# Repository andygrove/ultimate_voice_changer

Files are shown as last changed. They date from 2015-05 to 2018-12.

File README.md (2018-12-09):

# Ultimate Voice Changer Arduino Library

## What is this?

This is the official Arduino library for the Ultimate Voice Changer Arduino Shield, which is an open source hardware project that uses an MCP3208 ADC and an MCP4921 DAC with SPI communications to provide high quality voice sampling and real-time audio manipulation.

## Shield PCB

Eagle schematics and board layout for an Arduino Uno shield are included in this repository. Boards can also be purchased directly from OSH Park:

* [Ultimate Voice Changer PCB @ OSH Park](https://oshpark.com/shared_projects/ojPzRnSB)

## Component List

* [MCP3204](https://www.mouser.com/ProductDetail/579-MCP3204-CI-P)
* [MCP4921](https://www.mouser.com/ProductDetail/579-MCP4921-E-P)
* [Audio Jack](https://www.mouser.com/ProductDetail/502-35RAPC4BHN2)
* 1K resistor
* 1.5K resistor
* 330 ohm resistor
* 0.1 uF capacitor
* [10 uF electrolytic capacitor (2mm spacing)](https://www.mouser.com/ProductDetail/667-ECA-1HM100)
* [LED T1-3/4 (5mm) RED](https://www.mouser.com/ProductDetail/696-SLX-LX5093ID)
* [36-pin header](https://www.mouser.com/ProductDetail/538-22-28-4363)
* [10K Trimpot](https://www.sparkfun.com/products/9806)

## Example sketches

See the [examples](examples) directory for Dalek / ring modulator examples that mix voice input with a sine wave for robotic voice effects.

## Alternatives

I am no longer actively maintaining this project or providing support and I would suggest looking at the [Adafruit Wave Shield](https://learn.adafruit.com/wave-shield-voice-changer/overview) instead. They even have an example Dalek sketch.

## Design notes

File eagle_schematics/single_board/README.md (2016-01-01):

# Single Board Version

This is an experimental single-board version of the voice changer that incorporates an ATMEGA238P so that no separate Arduino board is required.

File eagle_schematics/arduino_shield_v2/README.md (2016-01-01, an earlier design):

# Arduino Shield

This directory contains Eagle schematics and board layout for an Arduino shield version of the voice changer that is compatible with the Arduino Uno R3.

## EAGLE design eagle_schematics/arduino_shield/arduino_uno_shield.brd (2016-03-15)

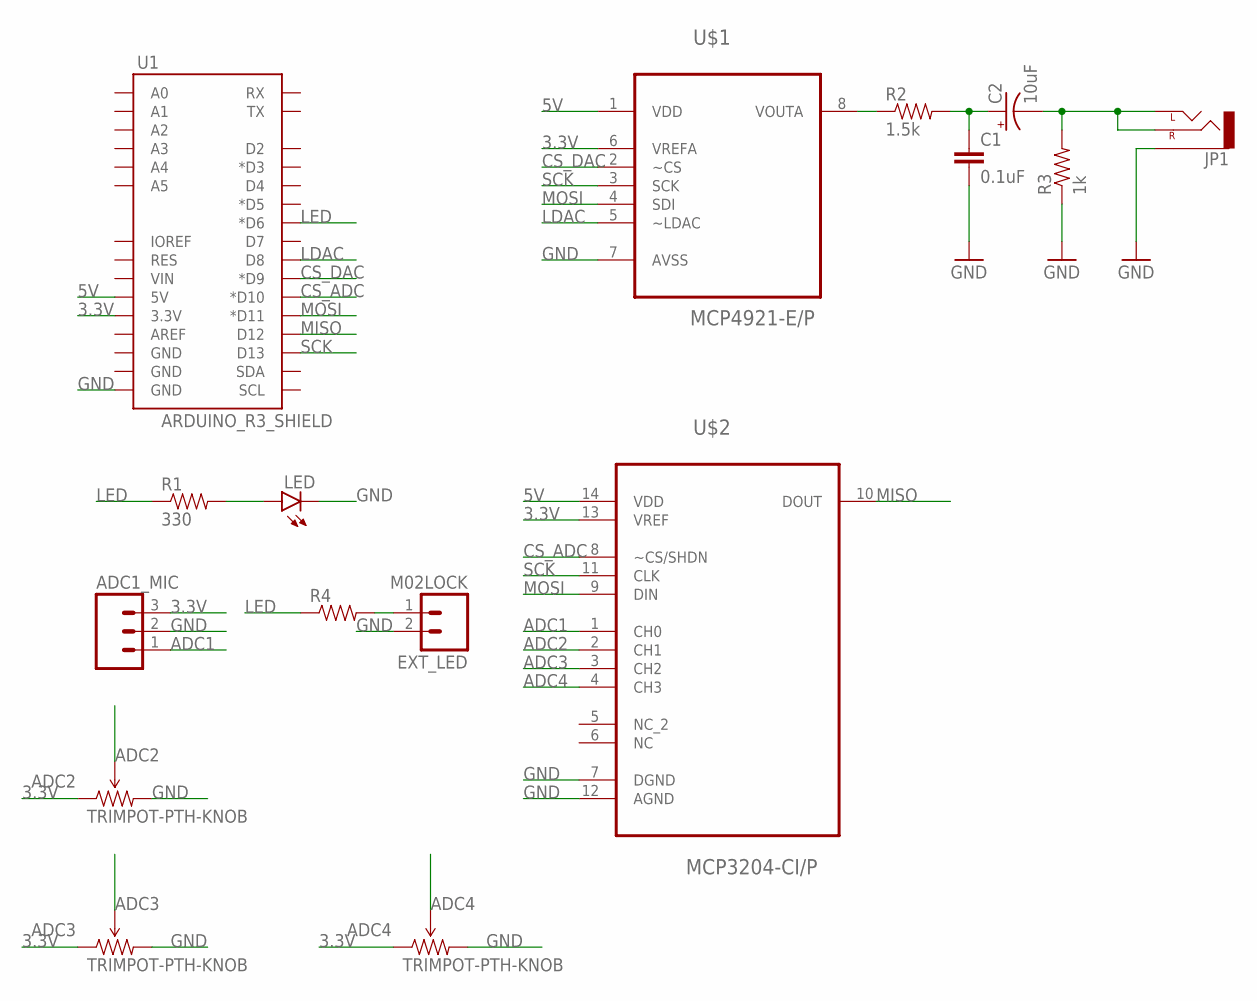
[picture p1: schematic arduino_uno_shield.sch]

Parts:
ADC1_MIC: M03LOCK; 1X03_LOCK
ADC2, ADC3, ADC4: TRIMPOT-PTH-KNOB; 3386U
C1: 0.1uF; CAP-PTH-5MM
C2: 10uF; CPOL-RADIAL-10UF-25V
EXT_LED: M02LOCK; 1X02_LOCK
JP1: AUDIO-JACKPTH; AUDIO-JACK
LED: LED5MM
R1: 330; AXIAL-0.4
R2: 1.5k; AXIAL-0.4
R3: 1k; AXIAL-0.4
R4: RESISTORPTH-1/4W; AXIAL-0.4
U1: ARDUINO_R3_SHIELD; UNO_R3_SHIELD
U$1: MCP4921-E/P; DIP254P762X432-8
U$2: MCP3204-CI/P; DIP254P762X432-14

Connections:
3.3V: ADC1_MIC.3, ADC2.1 (CCW), ADC3.1 (CCW), ADC4.1 (CCW), U1.3.3V, U$1.6 (VREFA), U$2.13 (VREF)
5V: U1.5V, U$1.1 (VDD), U$2.14 (VDD)
ADC1: ADC1_MIC.1, U$2.1 (CH0)
ADC2: ADC2.2 (WIPER), U$2.2 (CH1)
ADC3: ADC3.2 (WIPER), U$2.3 (CH2)
ADC4: ADC4.2 (WIPER), U$2.4 (CH3)
CS_ADC: U1.D10 (*D10), U$2.8 (~CS/SHDN)
CS_DAC: U1.D9 (*D9), U$1.2 (~CS)
GND: ADC1_MIC.2, ADC2.3 (CW), ADC3.3 (CW), ADC4.3 (CW), C1.2, EXT_LED.2, JP1.SLEEVE, LED.K (C), R3.P$1 (1), U1.GND@0 (GND), U$1.7 (AVSS), U$2.7 (DGND), U$2.12 (AGND)
LDAC: U1.D8, U$1.5 (~LDAC)
LED: R1.P$1 (1), R4.P$1 (1), U1.D6 (*D6)
MISO: U1.D12, U$2.10 (DOUT)
MOSI: U1.D11 (*D11), U$1.4 (SDI), U$2.9 (DIN)
unnamed: LED.A, R1.P$2 (2)
unnamed: R2.P$1 (1), U$1.8 (VOUTA)
unnamed: C1.1, C2.1 (+), R2.P$2 (2)
unnamed: C2.2 (-), JP1.RING (RIGHT), JP1.TIP (LEFT), R3.P$2 (2)
unnamed: EXT_LED.1, R4.P$2 (2)
SCK: U1.D13, U$1.3 (SCK), U$2.11 (CLK)

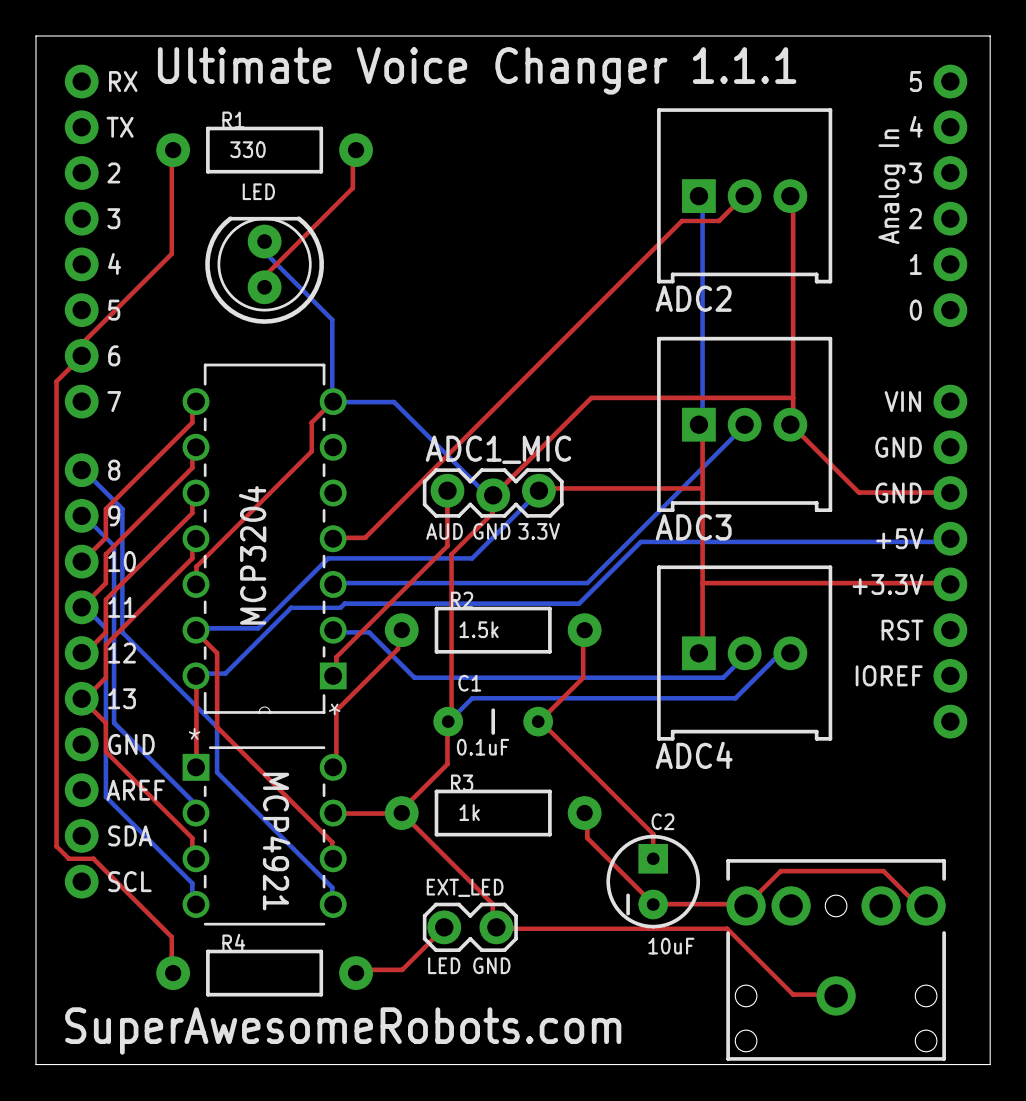
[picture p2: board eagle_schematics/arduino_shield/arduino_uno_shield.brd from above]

Board: 2 copper layers, 53.0 x 57.1 mm, 16 parts (0 on the bottom side), 19 nets.

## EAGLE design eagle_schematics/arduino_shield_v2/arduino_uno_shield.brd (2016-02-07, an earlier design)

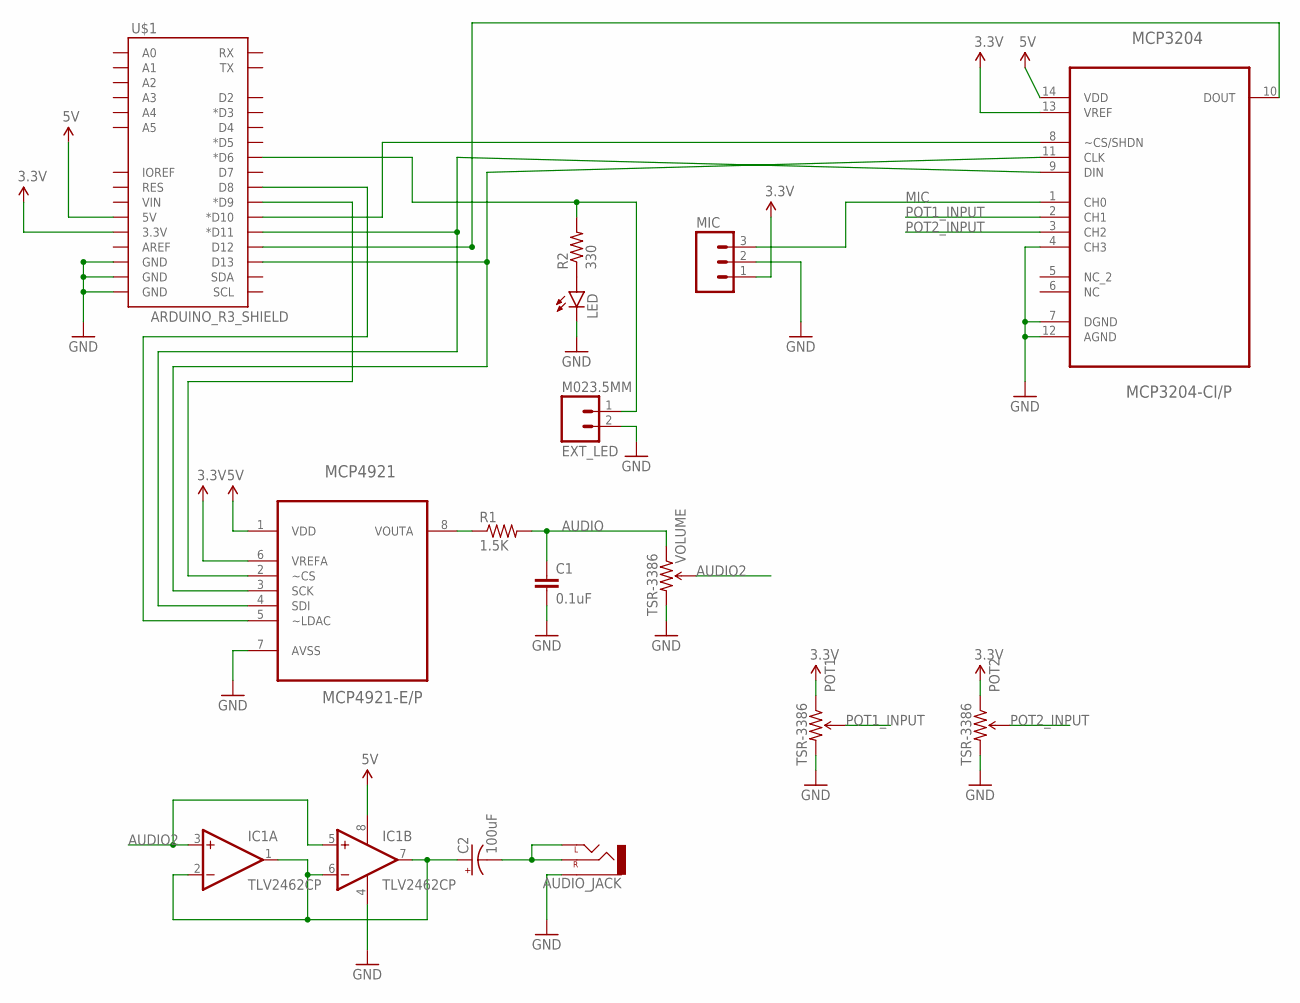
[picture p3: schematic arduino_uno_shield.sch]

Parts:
AUDIO_JACK: AUDIO-JACKPTH; AUDIO-JACK
C1: 0.1uF; CAP-PTH-SMALL
C2: 100uF; CPOL-RADIAL-100UF-25V
EXT_LED: M023.5MM; SCREWTERMINAL-3.5MM-2
IC1: TLV2462CP; DIL08
LED: LED5MM
MCP3204: MCP3204-CI/P; DIP254P762X432-14
MCP4921: MCP4921-E/P; DIP254P762X432-8
MIC: M03PTH; 1X03
POT1, POT2: TSR-3386; 3386U
R1: 1.5K; AXIAL-0.4
R2: 330; AXIAL-0.4
U$1: ARDUINO_R3_SHIELD; UNO_R3_SHIELD
VOLUME: TSR-3386; 3386U

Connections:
3.3V: MCP3204.13 (VREF), MCP4921.6 (VREFA), MIC.1, POT1.1 (CCW), POT2.1 (CCW), U$1.3.3V
5V: IC1.8 (V+), MCP3204.14 (VDD), MCP4921.1 (VDD), U$1.5V
AUDIO: C1.1, R1.P$2 (2), VOLUME.1 (CCW)
AUDIO2: IC1.3 (+IN), IC1.5 (+IN), VOLUME.2 (WIPER)
CS_ADC: MCP3204.8 (~CS/SHDN), U$1.D10 (*D10)
CS_DAC: MCP4921.2 (~CS), U$1.D9 (*D9)
GND: AUDIO_JACK.SLEEVE, C1.2, EXT_LED.2, IC1.4 (V-), LED.K (C), MCP3204.4 (CH3), MCP3204.7 (DGND), MCP3204.12 (AGND), MCP4921.7 (AVSS), MIC.2, POT1.3 (CW), POT2.3 (CW), U$1.GND@0 (GND), U$1.GND@1 (GND), U$1.GND@2 (GND), VOLUME.3 (CW)
MIC: MCP3204.1 (CH0), MIC.3
unnamed: MCP4921.8 (VOUTA), R1.P$1 (1)
unnamed: C2.1 (+), IC1.1 (OUT), IC1.2 (-IN), IC1.6 (-IN), IC1.7 (OUT)
unnamed: AUDIO_JACK.RING (RIGHT), AUDIO_JACK.TIP (LEFT), C2.2 (-)
unnamed: LED.A, R2.P$1 (1)
unnamed: MCP4921.5 (~LDAC), U$1.D8
unnamed: EXT_LED.1, R2.P$2 (2), U$1.D6 (*D6)
POT1_INPUT: MCP3204.2 (CH1), POT1.2 (WIPER)
POT2_INPUT: MCP3204.3 (CH2), POT2.2 (WIPER)
SPI_CLK: MCP3204.11 (CLK), MCP4921.3 (SCK), U$1.D13
SPI_MISO: MCP3204.10 (DOUT), U$1.D12
SPI_MOSI: MCP3204.9 (DIN), MCP4921.4 (SDI), U$1.D11 (*D11)

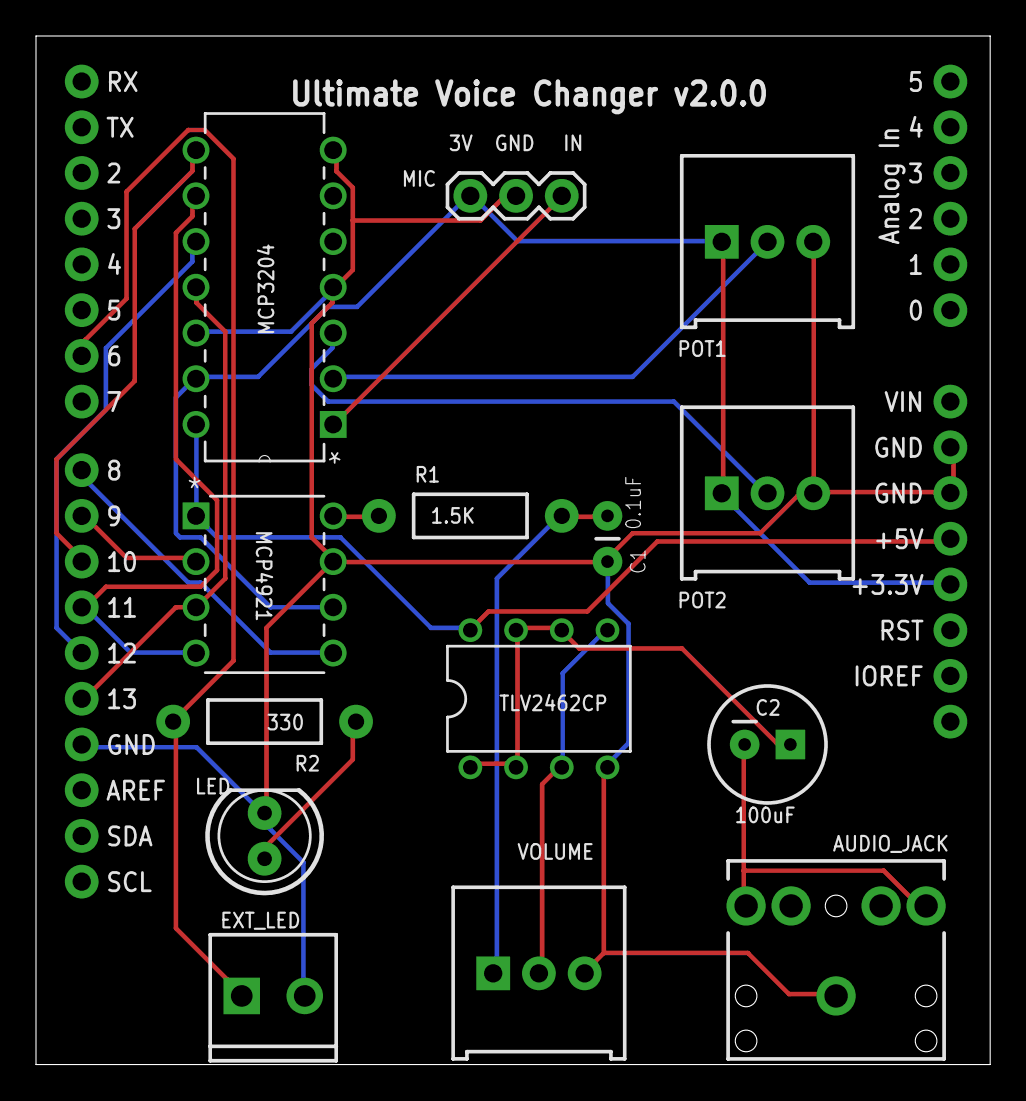
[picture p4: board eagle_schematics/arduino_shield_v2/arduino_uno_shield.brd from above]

Board: 2 copper layers, 53.0 x 57.1 mm, 15 parts (0 on the bottom side), 19 nets.

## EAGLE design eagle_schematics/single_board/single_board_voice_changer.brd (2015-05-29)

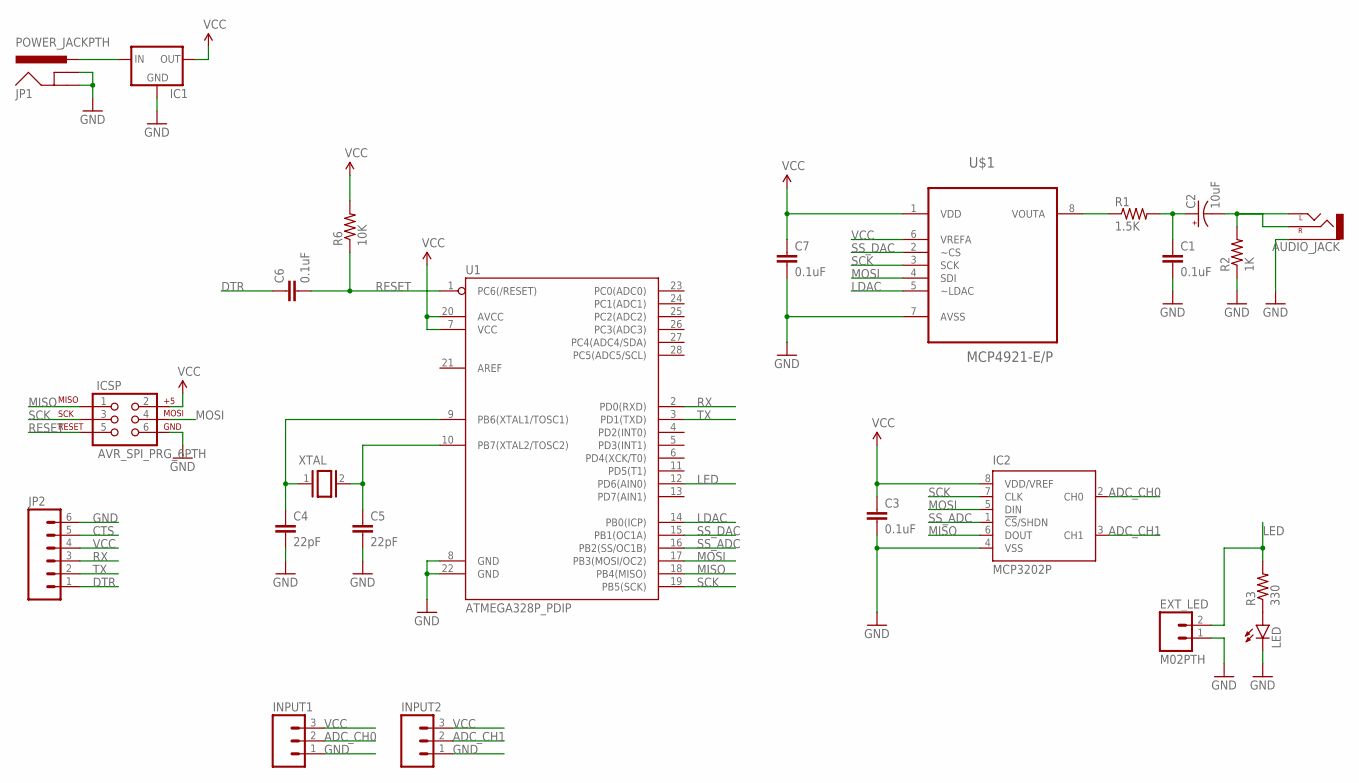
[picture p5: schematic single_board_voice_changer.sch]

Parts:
AUDIO_JACK: AUDIO-JACKPTH; AUDIO-JACK
C1, C3, C6, C7: 0.1uF; CAP-PTH-SMALL
C2: 10uF; CPOL-RADIAL-10UF-25V
C4, C5: 22pF; CAP-PTH-SMALL
EXT_LED: M02PTH; 1X02
IC1: V_REG_78XXSIDE; 78XXL
IC2: MCP3202P; DIL8
ICSP: AVR_SPI_PRG_6PTH; 2X3
INPUT1, INPUT2: M03PTH; 1X03
JP1: POWER_JACKPTH; POWER_JACK_PTH
JP2: M06SILK_FEMALE_PTH; 1X06
LED: LED5MM
R1: 1.5K; AXIAL-0.4
R2: 1K; AXIAL-0.4
R3: 330; AXIAL-0.4
R6: 10K; AXIAL-0.4
U1: ATMEGA328P_PDIP; DIL28-3
U$1: MCP4921-E/P; DIP254P762X432-8
XTAL: XTAL/S; QS

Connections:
ADC_CH0: IC2.2 (CH0), INPUT1.2
ADC_CH1: IC2.3 (CH1), INPUT2.2
CTS: JP2.5
DTR: C6.1, JP2.1
GND: AUDIO_JACK.SLEEVE, C1.2, C3.2, C4.2, C5.2, C7.2, EXT_LED.1, IC1.GND, IC2.4 (VSS), ICSP.6, INPUT1.1, INPUT2.1, JP1.GND, JP1.GNDBREAK, JP2.6, LED.K (C), R2.P$1 (1), U1.8 (GND), U1.22 (GND), U$1.7 (AVSS)
LDAC: U1.14 (PB0(ICP)), U$1.5 (~LDAC)
LED: EXT_LED.2, R3.P$2 (2), U1.12 (PD6(AIN0))
MISO: IC2.6 (DOUT), ICSP.1, U1.18 (PB4(MISO))
MOSI: IC2.5 (DIN), ICSP.4, U1.17 (PB3(MOSI/OC2)), U$1.4 (SDI)
unnamed: R1.P$1 (1), U$1.8 (VOUTA)
unnamed: C1.1, C2.1 (+), R1.P$2 (2)
unnamed: LED.A, R3.P$1 (1)
unnamed: IC1.IN, JP1.PWR
unnamed: C4.1, U1.9 (PB6(XTAL1/TOSC1)), XTAL.1
unnamed: C5.1, U1.10 (PB7(XTAL2/TOSC2)), XTAL.2
unnamed: AUDIO_JACK.RING (RIGHT), AUDIO_JACK.TIP (LEFT), C2.2 (-), R2.P$2 (2)
RESET: C6.2, ICSP.5, R6.P$1 (1), U1.1 (PC6(/RESET))
RX: JP2.3, U1.2 (PD0(RXD))
SCK: IC2.7 (CLK), ICSP.3, U1.19 (PB5(SCK)), U$1.3 (SCK)
SS_ADC: IC2.1 (!CS!/SHDN), U1.16 (PB2(SS/OC1B))
SS_DAC: U1.15 (PB1(OC1A)), U$1.2 (~CS)
TX: JP2.2, U1.3 (PD1(TXD))
VCC: C3.1, C7.1, IC1.OUT, IC2.8 (VDD/VREF), ICSP.2, INPUT1.3, INPUT2.3, JP2.4, R6.P$2 (2), U1.7 (VCC), U1.20 (AVCC), U$1.1 (VDD), U$1.6 (VREFA)

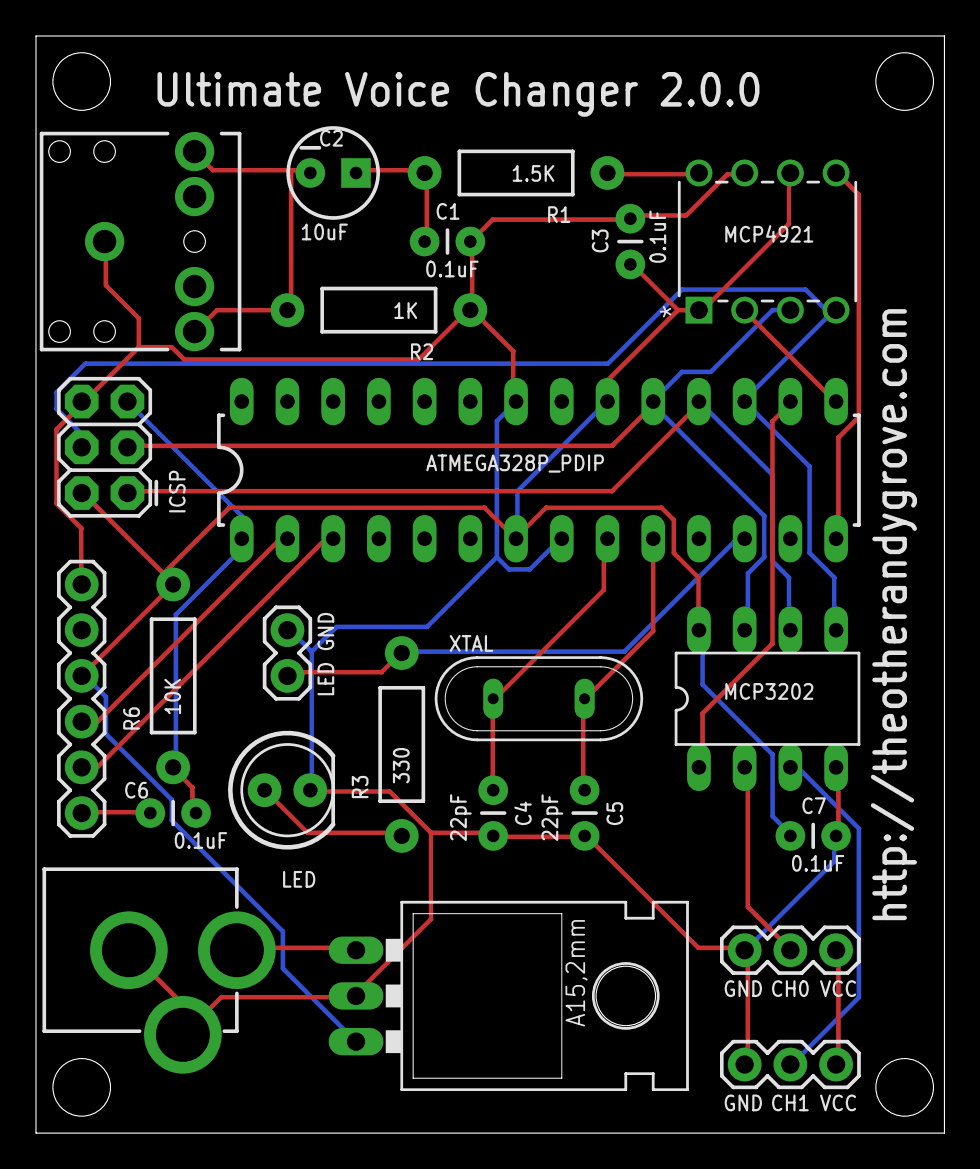
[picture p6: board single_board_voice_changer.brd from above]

Board: 2 copper layers, 50.5 x 61.0 mm, 24 parts (0 on the bottom side), 22 nets.

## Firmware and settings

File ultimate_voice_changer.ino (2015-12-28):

/**
 * Ultimate Voice Changer for Arduino
 * Created by Andy Grove.
 *
 * Requires an external board/shield hosting an MCP3208 ADC 
 * and an MCP4921 DAC as well as a few passive components and
 * an audio jack.
 *
 * For more information, please visit the project page:
 *
 * http://theotherandygrove.com/projects/ultimate-voice-changer-arduino-shield/
 */

// comment this out if you don't want the LED working
#define ENABLE_LED 

// comment this out if you don't have a pot attached to the second input
#define ENABLE_POT

// the code now supports some different effects modes, mostly to help with debugging
#define MODE_NO_EFFECT 1 // this mode passes the mic input directly to the audio out without modification
#define MODE_RING_MOD  2 // this is the default ring modulator mode where the mic input is mixed with a sine wave then written to audio out
#define MODE_SINE_WAVE 3 // this mode writes the sine wave directly to audio out

const int mode = MODE_RING_MOD;

// number of points in sine wave data
#define NUM_SINE_WAVE_POINTS 1024

// PORTD pin assignments
const int PORTD_LED = 6;

// uncomment this line to use MCP3202 instead of MCP3204/8
//#define MCP3202

// PORTB pin assignments
const int LDAC = 0;     // Arduino pin 8
const int CS_DAC = 1;   // Arduino pin 9
const int CS_ADC = 2;   // Arduino pin 10
const int DATAOUT = 3;  // Arduino pin 11
const int DATAIN = 4;   // Arduino pin 12
const int SPICLOCK = 5; // Arduino pin 13

// SPI command for DAC
const int cmd = 0x7000;

// threshold for tuning sensitivity of LED response to sound levels
const int threshold = 256;

int index = 0;
int fword;
int data;
int counter = 0;
long last_time = 0;

// speed to iterate over sine wave .. changing this affects the frequency
int incr = 2;

// this variable is used for the LED PWM effect
int sound_level = 0;
int led_counter = 0;
int sample_counter = 0;
int audio_in = 0;
int audio_out = 0;
int dc_offset = 2063;

byte sineWave[NUM_SINE_WAVE_POINTS];  

void setup() {
  
  // prepare sine wave
  fill_sinewave();

  delay(1000);

  cli();
  
  // set digital pin 6 to output for the LEDs
  DDRD |= _BV(PORTD_LED);

  // LDAC, CS_DAC, CS_ADC, DATAOUT to OUTPUT
  DDRB |= _BV(LDAC);
  DDRB |= _BV(CS_ADC);
  DDRB |= _BV(CS_DAC);
  DDRB |= _BV(DATAOUT);
  DDRB |= _BV(SPICLOCK);

  // set DATAIN to INPUT
  DDRB &= ~_BV(DATAIN);

  // disable both the ADC and DAC by writing them HIGH
  PORTB |= _BV(CS_ADC);
  PORTB |= _BV(CS_DAC);

  // set the clock low
  PORTB &= ~_BV(SPICLOCK);
  
  // turn the LED on briefly to show startup
  PORTD |= _BV(PORTD_LED);
  delay(500);
  PORTD &= ~_BV(PORTD_LED);
}

/** Set CLK HIGH then LOW */
inline void cycle_clock() {
  PORTB |= _BV(SPICLOCK);
  PORTB &= ~_BV(SPICLOCK);
}

/** Read from ADC */
int read_adc_mcp3202(int channel){

  int adcvalue = 0;

  // command bits - start, sgl/diff, odd/sign, channel 0, channel 1
  byte commandbits = B11010000; 

  // allow channel selection
  commandbits|=((channel-1)<<5);

  // select ADC
  PORTB &= ~_BV(CS_ADC);

  // setup bits to be written
  for (int i=7; i>=4; i--){
    if (commandbits&1<<i) {
      PORTB |= _BV(DATAOUT);
    } else {
      PORTB &= ~_BV(DATAOUT);
    }
    cycle_clock();
  }

  //cycle clock to ignore null bit
  cycle_clock();

  //read bits from adc
  for (int i=11; i>=0; i--){
    adcvalue += ((PINB & _BV(DATAIN)) >> 4) << i;
    cycle_clock();
  }

  PORTB |= _BV(CS_ADC);

  return adcvalue;
}

/** Read from ADC */
int read_adc_mcp3208(int channel){

  int adcvalue = 0;

  // command bits - start, mode, chn (3), dont care (3)
  byte commandbits = B11000000; 

  // allow channel selection
  commandbits|=((channel-1)<<3);

  // select ADC
  PORTB &= ~_BV(CS_ADC);

  // setup bits to be written
  for (int i=7; i>=3; i--){
    if (commandbits&1<<i) {
      PORTB |= _BV(DATAOUT);
    } else {
      PORTB &= ~_BV(DATAOUT);
    }
    cycle_clock();
  }

  //cycle clock twice to ignore two null bits
  cycle_clock();
  cycle_clock();

  //read bits from adc
  for (int i=11; i>=0; i--){
    adcvalue += ((PINB & _BV(DATAIN)) >> 4) << i;
    cycle_clock();
  }

  PORTB |= _BV(CS_ADC);

  return adcvalue;
}

int read_adc(int channel){
#ifdef MCP3202
  return read_adc_mcp3202(channel);
#else
  return read_adc_mcp3208(channel);
#endif
}

/** Write to DAC */
void write_dac(int data) {

  // combine command and data
  fword = cmd | data;
  
  // chip select
  PORTB &= ~_BV(CS_DAC);
  
  // start writing data
  PORTB |= _BV(LDAC);

  for (int i1=0; i1<16; i1++) {
    if (fword & 0x8000) {
      PORTB |= _BV(DATAOUT);
    } else {
      PORTB &= ~_BV(DATAOUT);
    }

    cycle_clock();

    fword = fword << 1; 
  }

  // end of conversion
  PORTB |= _BV(CS_DAC);
  
  // writing data to output buffer
  PORTB &= ~_BV(LDAC);
}

void loop() {

  ++sample_counter;

  if (sample_counter == 400) {
    sample_counter = 0;
    
#ifdef ENABLE_POT
    int pot = read_adc(2);
    incr = 1 + (pot/128);
#endif

  } else {
    // sample audio input
    audio_in = read_adc(1);
  }

  // get next point in sine wave table
  index += incr;
  if (index >= NUM_SINE_WAVE_POINTS)  {
    index -= NUM_SINE_WAVE_POINTS;
  }
  data = sineWave[index];

  // mix audio with sine wave
  if (mode == MODE_SINE_WAVE) {
    audio_in = 4095;
    audio_out = 2047 + ((audio_in-dc_offset) * ((data-127) / 127.0));
  } else if (mode == MODE_RING_MOD) {
    audio_out = 2047 + ((audio_in-dc_offset) * ((data-127) / 127.0));
  } else {
    audio_out = audio_in;
  }
  
#ifdef ENABLE_LED

  if (audio_in > 2048+threshold || audio_in < 2048-threshold) {
    sound_level = 255;
  } else {
    if (sound_level > 0) {
      sound_level -= 1;
    }
  }
  
  // crude way to simulate PWM effect, this could be improved by using interrupts
  if (++led_counter > 255) {
    led_counter = 0;
  }
  if (led_counter < sound_level) {
    PORTD |= _BV(PORTD_LED);
  } else {
    PORTD &= ~_BV(PORTD_LED);
  }

#endif

  // clip the signal
  if (audio_out<0) audio_out = 0;
  else if (audio_out>4095) audio_out = 4095;

  // attempt to reduce noise
  if (audio_out > 2030 && audio_out < 2100) {
    audio_out = 2047;
  }
  
  // write output
  write_dac(audio_out);
}

void fill_sinewave(){
  float pi = 3.141592;
  float dx = dx = 2 * pi / NUM_SINE_WAVE_POINTS;   // fill the  byte bufferarry
  float fd = 0;
  float fcnt = 0;
  int iw;
  for (iw = 0; iw < NUM_SINE_WAVE_POINTS; iw++){      // with 50 periods sinewawe
    fd= 127*sin(fcnt);                // fundamental tone
    fcnt=fcnt+dx;                     // in the range of 0 to 2xpi  and 1/512 increments
    int bb=127+fd;                        // add dc offset to sinewawe 
    sineWave[iw]=bb;                  // write value into array
    // uncomment this to see the sine wave numbers in the serial monitor
    
    Serial.print("Sine: ");
    Serial.println(bb);
    
  }
}    
    

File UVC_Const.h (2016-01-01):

#define LDAC     0 // Arduino pin 8
#define CS_DAC   1 // Arduino pin 9
#define CS_ADC   2 // Arduino pin 10
#define DATAOUT  3 // Arduino pin 11
#define DATAIN   4 // Arduino pin 12
#define SPICLOCK 5 // Arduino pin 13

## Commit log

2014-10-11 initial checkin of sample code
2014-10-11 now reads from adc and passes value to dac
2014-10-11 blink LED to show sampling rate
2014-10-20 started on schematics
    [arduino_uno_shield.sch]
2014-10-20 wiring up schematic
    [arduino_uno_shield.sch]
2014-10-20 first attempt at board layout
    [arduino_uno_shield.brd, arduino_uno_shield.sch]
2014-10-20 removed board
    [arduino_uno_shield.brd, arduino_uno_shield.sch]
2014-10-20 re-created board
    [arduino_uno_shield.brd, arduino_uno_shield.sch]
2014-10-21 clean up board layout
    [arduino_uno_shield.brd, arduino_uno_shield.sch]
2014-10-21 add more pot headers
    [arduino_uno_shield.brd, arduino_uno_shield.sch]
2014-10-21 created board from scratch
    [arduino_uno_shield.brd, arduino_uno_shield.sch]
2014-10-21 fixed polarity issue on LED screw terminal
    [arduino_uno_shield.brd, arduino_uno_shield.sch]
2014-10-21 save latest
    [arduino_uno_shield.brd, arduino_uno_shield.sch]
2014-10-29 first cut of AVR version
2014-11-02 enable LED
2014-11-03 changed layout to reduce interference
    [arduino_uno_shield.brd]
2014-11-03 add branding
    [arduino_uno_shield.brd]
2014-11-14 refining board layout to remove via:
    [arduino_uno_shield.brd]
2014-11-14 saving work, this version ordered
    [arduino_uno_shield.brd]
2014-12-29 roughing out pre-amp schematic
    [dynamic_mic_preamp.sch]
2014-12-30 udpated schematic for pre-amp
    [dynamic_mic_preamp.sch]
2015-04-02 started work on single board version
    [dynamic_mic_preamp.sch, single_board_voice_changer.sch]
2015-05-03 working on single board version
    [single_board_voice_changer.brd, single_board_voice_changer.sch]
2015-05-03 board with no ground plane, 0
    [single_board_voice_changer.brd]
2015-05-03 price down to 8.77
    [single_board_voice_changer.brd]
2015-05-08 add support for MCP3202 ADC
2015-05-12 change ADC to MCP3202
    [single_board_voice_changer.brd, single_board_voice_changer.sch]
2015-05-12 redo board
    [single_board_voice_changer.brd]
2015-05-13 another rev of the board design
    [single_board_voice_changer.brd]
2015-05-13 consistent fonts
    [single_board_voice_changer.brd, single_board_voice_changer.sch]
2015-05-29 fix error with schematic
    [single_board_voice_changer.brd, single_board_voice_changer.sch]
2015-12-28 add noise canceling code
    [ultimate_voice_changer.ino]
2016-01-01 restruture repo
    [arduino_uno_shield.brd, arduino_uno_shield.sch, dynamic_mic_preamp.sch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]
2016-01-02 Add Dalek sketch with fixed frequencies
    [dalek.ino]
2016-01-03 start work on new version of shield
    [arduino_uno_shield.brd, arduino_uno_shield.sch]
2016-01-03 add amplifier
    [arduino_uno_shield.brd, arduino_uno_shield.sch]
2016-01-03 working on new board layout with trimpots
    [arduino_uno_shield.brd, arduino_uno_shield.sch]
2016-01-03 change to MCP3204 with 2 trimpot inputs
    [arduino_uno_shield.brd, arduino_uno_shield.sch]
2016-01-04 refine board layout
    [arduino_uno_shield.brd, arduino_uno_shield.sch]
2016-03-01 new board rev
    [v110.brd, v110.sch]
2016-03-03 clean up board
    [v110.brd, v110.sch]
2016-03-15 small refinement to board layout
    [arduino_uno_shield.brd]
2016-03-15 remove experimental designs
    [dynamic_mic_preamp.sch]
2016-03-15 change resistors from AXIAL-0.3 to AXIAL-0.4
    [arduino_uno_shield.brd, arduino_uno_shield.sch]
2016-06-09 update for version 1.1 of board (use channel 0 for pot instead of channel 2)

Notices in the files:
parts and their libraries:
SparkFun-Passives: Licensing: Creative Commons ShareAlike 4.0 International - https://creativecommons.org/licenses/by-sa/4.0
